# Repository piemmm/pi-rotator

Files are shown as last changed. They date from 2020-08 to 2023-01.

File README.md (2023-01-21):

# pi-rotator
The GS-232 costs far too much, so here's a simple Pi based antenna rotator which uses through-hole components wherever possible

The project is CC-BY-SA 

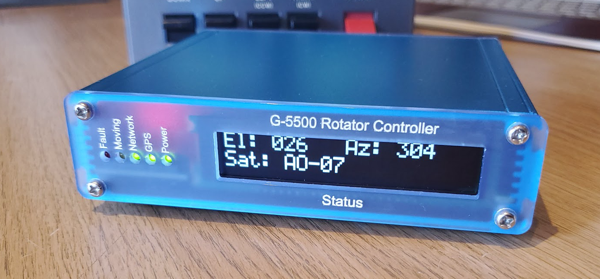
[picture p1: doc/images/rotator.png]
Picture of rotator

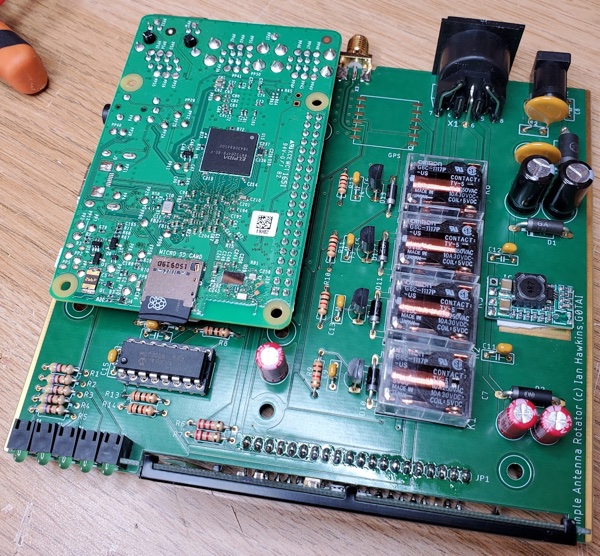
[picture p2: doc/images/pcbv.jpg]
Picture of rotator circuit board


This project is currently still EXPERIMENTAL until the board design is finalised, and the driver software made more useful.

Getting Started:

pirotator is installed in the default user home directory - you can change this if you want.

Create the pirotator directory and change into it:

````
mkdir /home/pi/pirotator
cd /home/pi/pirotator
````

extract the contents of the repository folder ./home/pirotator to /home/pi/pirotator (this contains config.xml, start.sh, etc)

Then, make start.sh executable (if it is not already):

````
chmod u+x start.sh
````

install java 8 (java11+ support available once pi4j is updated):
 
````
sudo apt install openjdk-8-jdk
````

Copy the pirotator.service to systemd (only if you want to start at boot):

````
sudo cp pirotator.service /etc/systemd/system/pirotator.service
````

Then, enable the service

````
sudo systemctl enable pirotator.service
````

After that you should be good to go and can type:

````
sudo service pirotator.service start
````

To enable PPS + GPS + NTPd so you can have your own stratum one equivalent server:

Install the relevant bits:

````
sudo apt install gpsd gpsd-clients python-gi-cairo pps-tools ntp
````

Add this to /boot/config.txt

````
dtoverlay=pps-gpio,gpiopin=4,capture_clear
````

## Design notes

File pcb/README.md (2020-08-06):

The PCB files are created with Eagle PCB and the design is CC-BY-SA.

This is still experimental.

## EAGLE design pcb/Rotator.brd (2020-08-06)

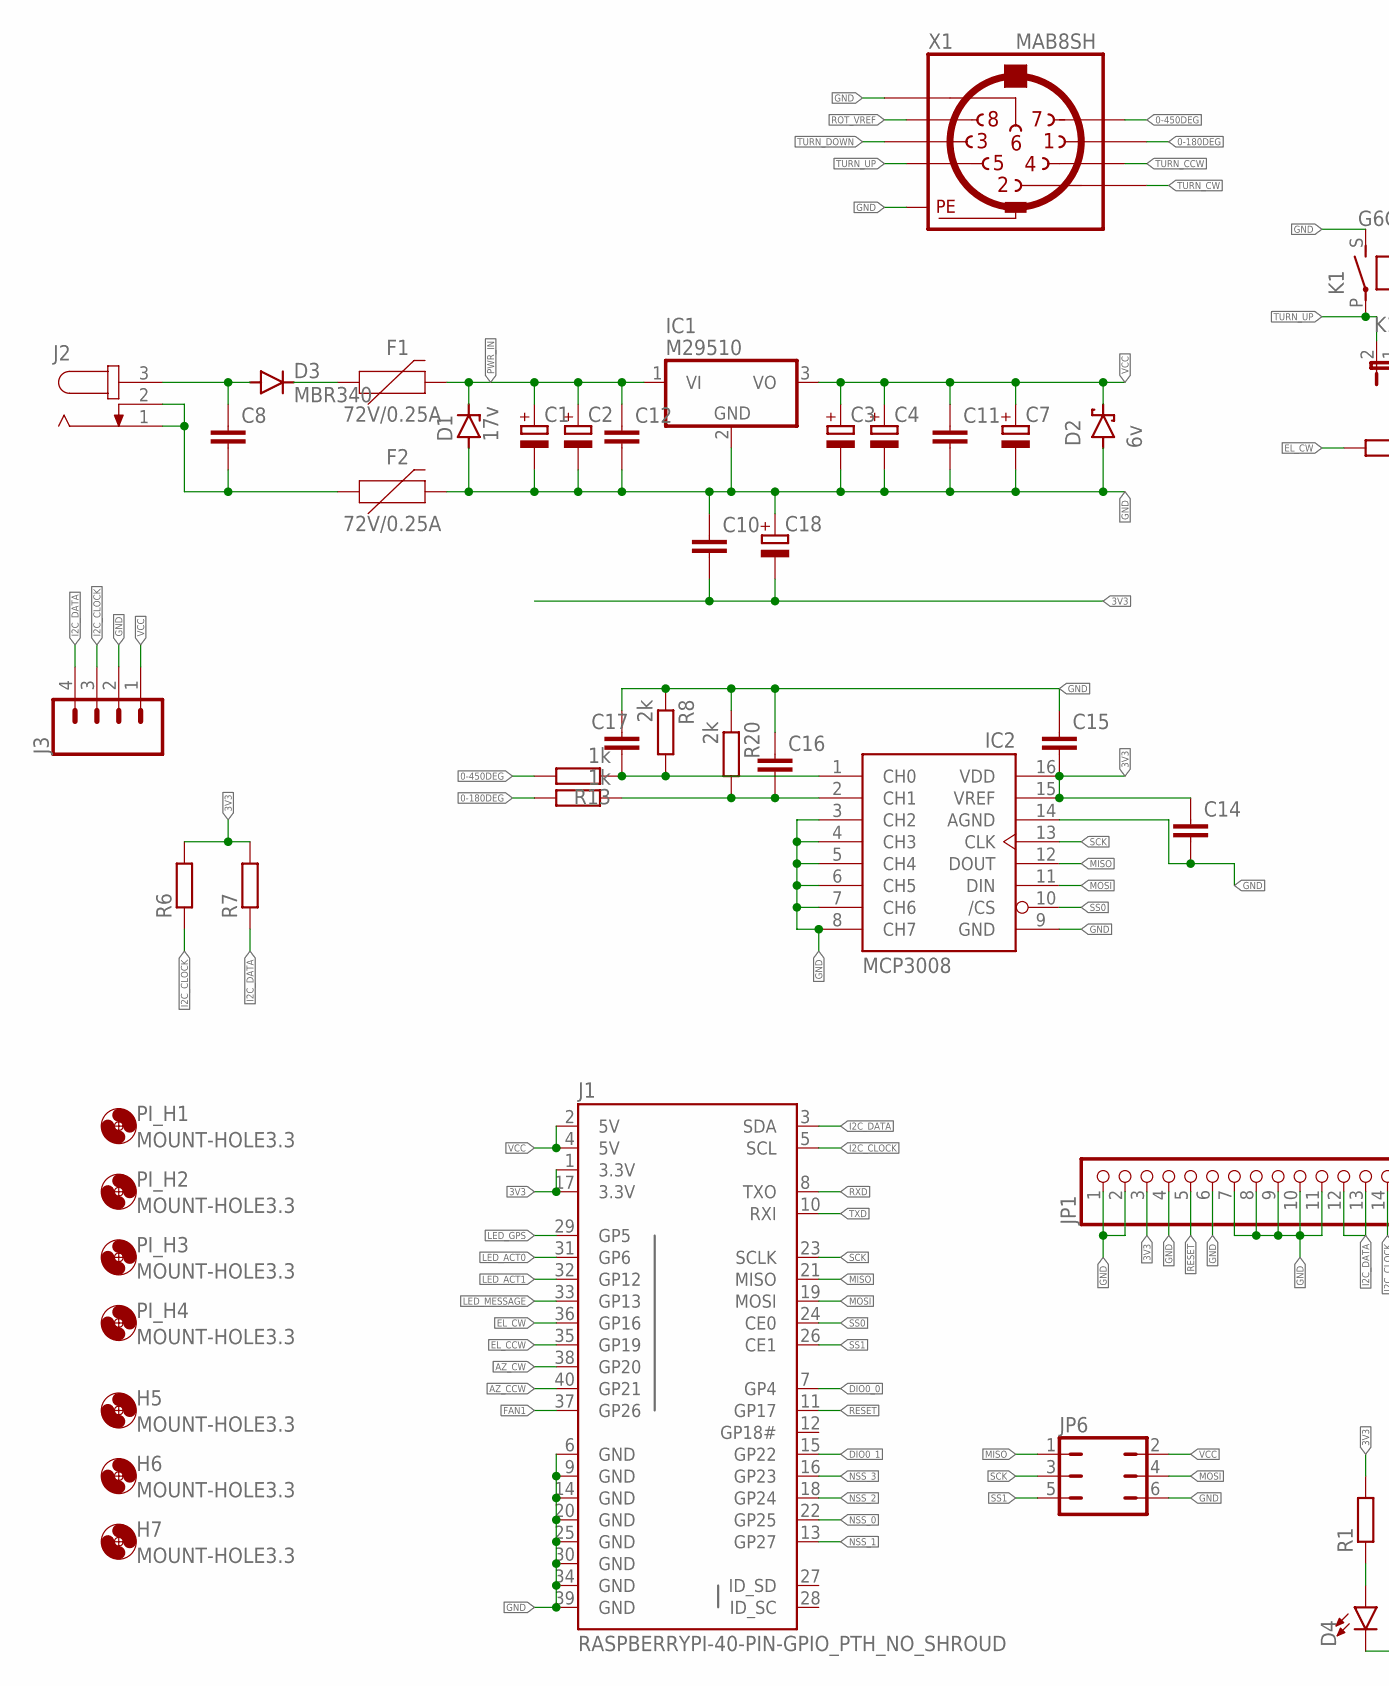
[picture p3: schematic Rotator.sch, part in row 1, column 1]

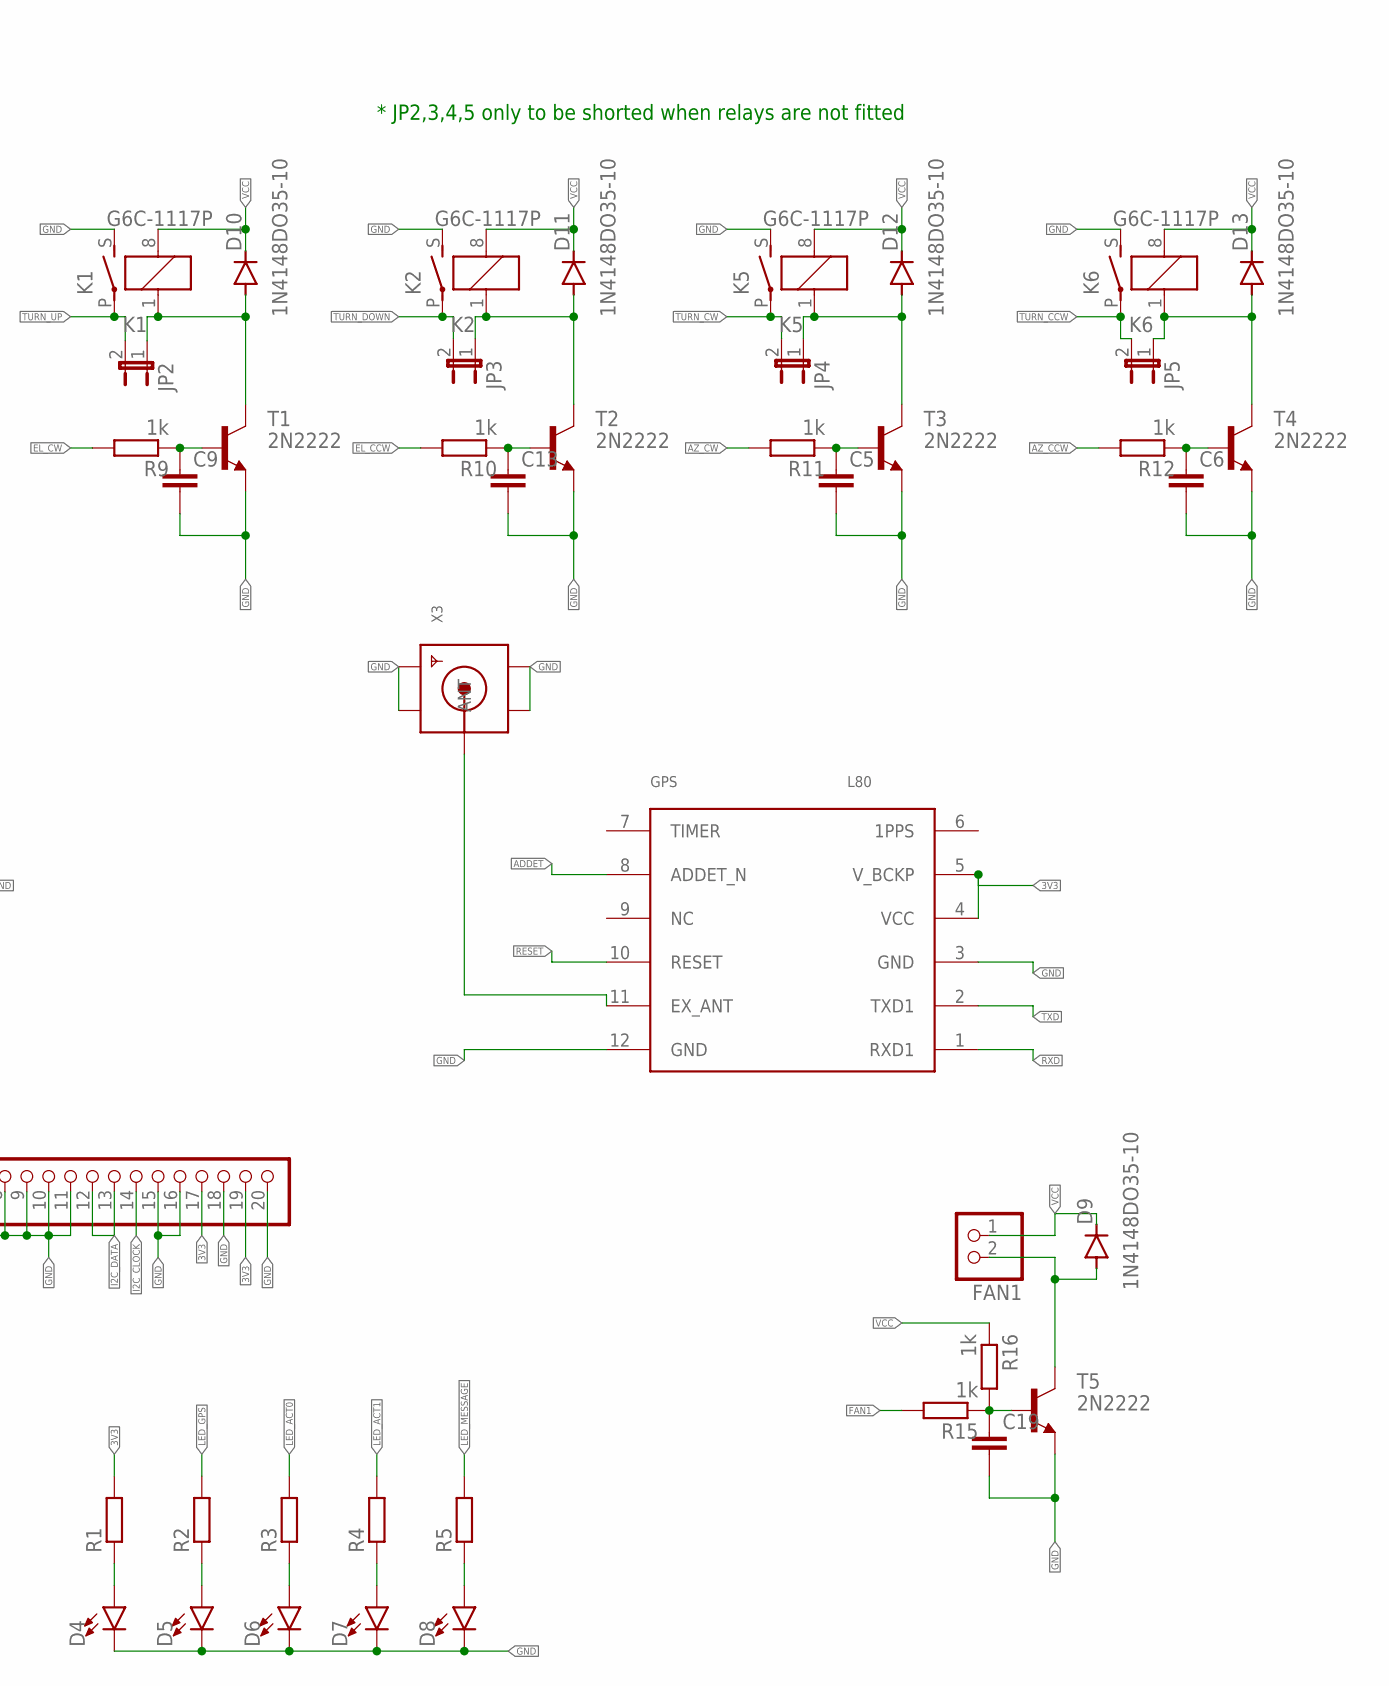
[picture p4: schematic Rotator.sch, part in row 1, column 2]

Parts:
C1, C2: CPOL-EUE5-8.5; E5-8,5
C3, C4, C7, C18: CPOL-EUE2.5-7; E2,5-7
C5, C6, C8, C9, C10, C11, C12, C13, C14, C15, C16, C17, C19: C-EU050-025X075; C050-025X075
D1: 17v; F126Z12
D2: 6v; F126Z12
D3: MBR340; DO201-15
D4, D5, D6, D7, D8: LED3MM; LED_3MM
D9, D10, D11, D12, D13: 1N4148DO35-10; DO35-10
F1, F2: 72V/0.25A; PTH
FAN1: JST_2PIN-THM; JST-PH-2-THM
GPS: L80
H5, H6, H7: MOUNT-HOLE3.3; 3,3
IC1: M29510; TO220H
IC2: MCP3008; DIL16
J1: RASPBERRYPI-40-PIN-GPIO_PTH_NO_SHROUD; 2X20
J2: JACK-PLUG0; SPC4077
J3: CONN_04; 1X04
JP1: PINHD-1X20; 1X20
JP2, JP3, JP4, JP5: JP1E; JP1
JP6: JP3Q
K1, K2, K5, K6: G6C-1117P
PI_H1, PI_H2, PI_H3, PI_H4: MOUNT-HOLE3.3; 3,3
R1, R2, R3, R4, R5, R6, R7: R-EU_0207/10; 0207/10
R8, R20: 2k; 0207/10
R9, R10, R11, R12, R13, R14, R15, R16: 1k; 0207/10
T1, T2, T3, T4, T5: 2N2222; TO92-EBC-OVAL
X1: MAB8SH
X3: SMACONNECTOR_EDGE; SMA_EDGELAUNCH

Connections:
0-180DEG: R14.2, X1.1
0-450DEG: R13.2, X1.7
3V3: C10.2, C14.1, C15.2, C18.-, GPS.4 (VCC), GPS.5 (V_BCKP), IC2.15 (VREF), IC2.16 (VDD), J1.1 (3.3V), J1.17 (3.3V), JP1.3, JP1.17, JP1.19, R1.2, R6.2, R7.2
ADDET: GPS.8 (ADDET_N)
AZ_CCW: J1.40 (GP21), R12.2
AZ_CW: J1.38 (GP20), R11.2
DIO0_0: J1.7 (GP4)
DIO0_1: J1.15 (GP22)
EL_CCW: J1.35 (GP19), R10.2
EL_CW: J1.36 (GP16), R9.2
FAN1: J1.37 (GP26), R15.2
FANHDR-: D9.A, FAN1.2 (1), T5.C
GND: C1.-, C2.-, C3.-, C4.-, C5.2, C6.2, C7.-, C9.2, C10.1, C11.2, C12.2, C13.2, C14.2, C15.1, C16.1, C17.1, C18.+, C19.2, D1.A, D2.A, D4.K (C), D5.K (C), D6.K (C), D7.K (C), D8.K (C), F2.P$2 (2), GPS.3 (GND), GPS.12 (GND), IC1.2 (GND), IC2.3 (CH2), IC2.4 (CH3), IC2.5 (CH4), IC2.6 (CH5), IC2.7 (CH6), IC2.8 (CH7), IC2.9 (GND), IC2.14 (AGND), J1.6 (GND), J1.9 (GND), J1.14 (GND), J1.20 (GND), J1.25 (GND), J1.30 (GND), J1.34 (GND), J1.39 (GND), J3.2, JP1.1, JP1.2, JP1.4, JP1.6, JP1.7, JP1.8, JP1.9, JP1.10, JP1.11, JP1.15, JP1.16, JP1.18, JP1.20, JP6.6, K1.S, K2.S, K5.S, K6.S, R8.1, R20.1, T1.E, T2.E, T3.E, T4.E, T5.E, X1.6, X1.PE, X1.PE@ (PE), X3.GND@1 (GND4), X3.GND@2 (GND3), X3.GND@3 (GND2), X3.GND@4 (GND1)
I2C_CLOCK: J1.5 (SCL), J3.3, JP1.14, R6.1
I2C_DATA: J1.3 (SDA), J3.4, JP1.12, JP1.13, R7.1
LED_ACT0: J1.31 (GP6), R3.2
LED_ACT1: J1.32 (GP12), R4.2
LED_GPS: J1.29 (GP5), R2.2
LED_MESSAGE: J1.33 (GP13), R5.2
MISO: IC2.12 (DOUT), J1.21 (MISO), JP6.1
MOSI: IC2.11 (DIN), J1.19 (MOSI), JP6.4
unnamed: C5.1, R11.1, T3.B
unnamed: D12.A, JP4.1, K5.1, T3.C
unnamed: C8.1, D3.A, J2.3
unnamed: C8.2, F2.P$1 (1), J2.1, J2.2
unnamed: GPS.11 (EX_ANT), X3.P (ANT)
unnamed: C13.1, R10.1, T2.B
unnamed: D3.C, F1.P$1 (1)
unnamed: C6.1, R12.1, T4.B
unnamed: C19.1, R15.1, R16.2, T5.B
unnamed: D13.A, JP5.1, K6.1, T4.C
unnamed: D4.A, R1.1
unnamed: D5.A, R2.1
unnamed: D6.A, R3.1
unnamed: D7.A, R4.1
unnamed: D8.A, R5.1
unnamed: C9.1, R9.1, T1.B
unnamed: D10.A, JP2.1, K1.1, T1.C
unnamed: D11.A, JP3.1, K2.1, T2.C
unnamed: C17.2, IC2.1 (CH0), R8.2, R13.1
unnamed: C16.2, IC2.2 (CH1), R14.1, R20.2
NSS_0: J1.22 (GP25)
NSS_1: J1.13 (GP27)
NSS_2: J1.18 (GP24)
NSS_3: J1.16 (GP23)
PWR_IN: C1.+, C2.+, C12.1, D1.C, F1.P$2 (2), IC1.1 (VI)
RESET: GPS.10 (RESET), J1.11 (GP17), JP1.5
ROT_VREF: X1.8
RXD: GPS.1 (RXD1), J1.8 (TXO)
SCK: IC2.13 (CLK), J1.23 (SCLK), JP6.3
SS0: IC2.10 (/CS), J1.24 (CE0)
SS1: J1.26 (CE1), JP6.5
TURN_CCW: JP5.2, K6.P, X1.4
TURN_CW: JP4.2, K5.P, X1.2
TURN_DOWN: JP3.2, K2.P, X1.3
TURN_UP: JP2.2, K1.P, X1.5
TXD: GPS.2 (TXD1), J1.10 (RXI)
VCC: C3.+, C4.+, C7.+, C11.1, D2.C, D9.C, D10.C, D11.C, D12.C, D13.C, FAN1.1 (2), IC1.3 (VO), J1.2 (5V), J1.4 (5V), J3.1, JP6.2, K1.8 (2), K2.8 (2), K5.8 (2), K6.8 (2), R16.1

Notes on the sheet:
* JP2,3,4,5 only to be shorted when relays are not fitted

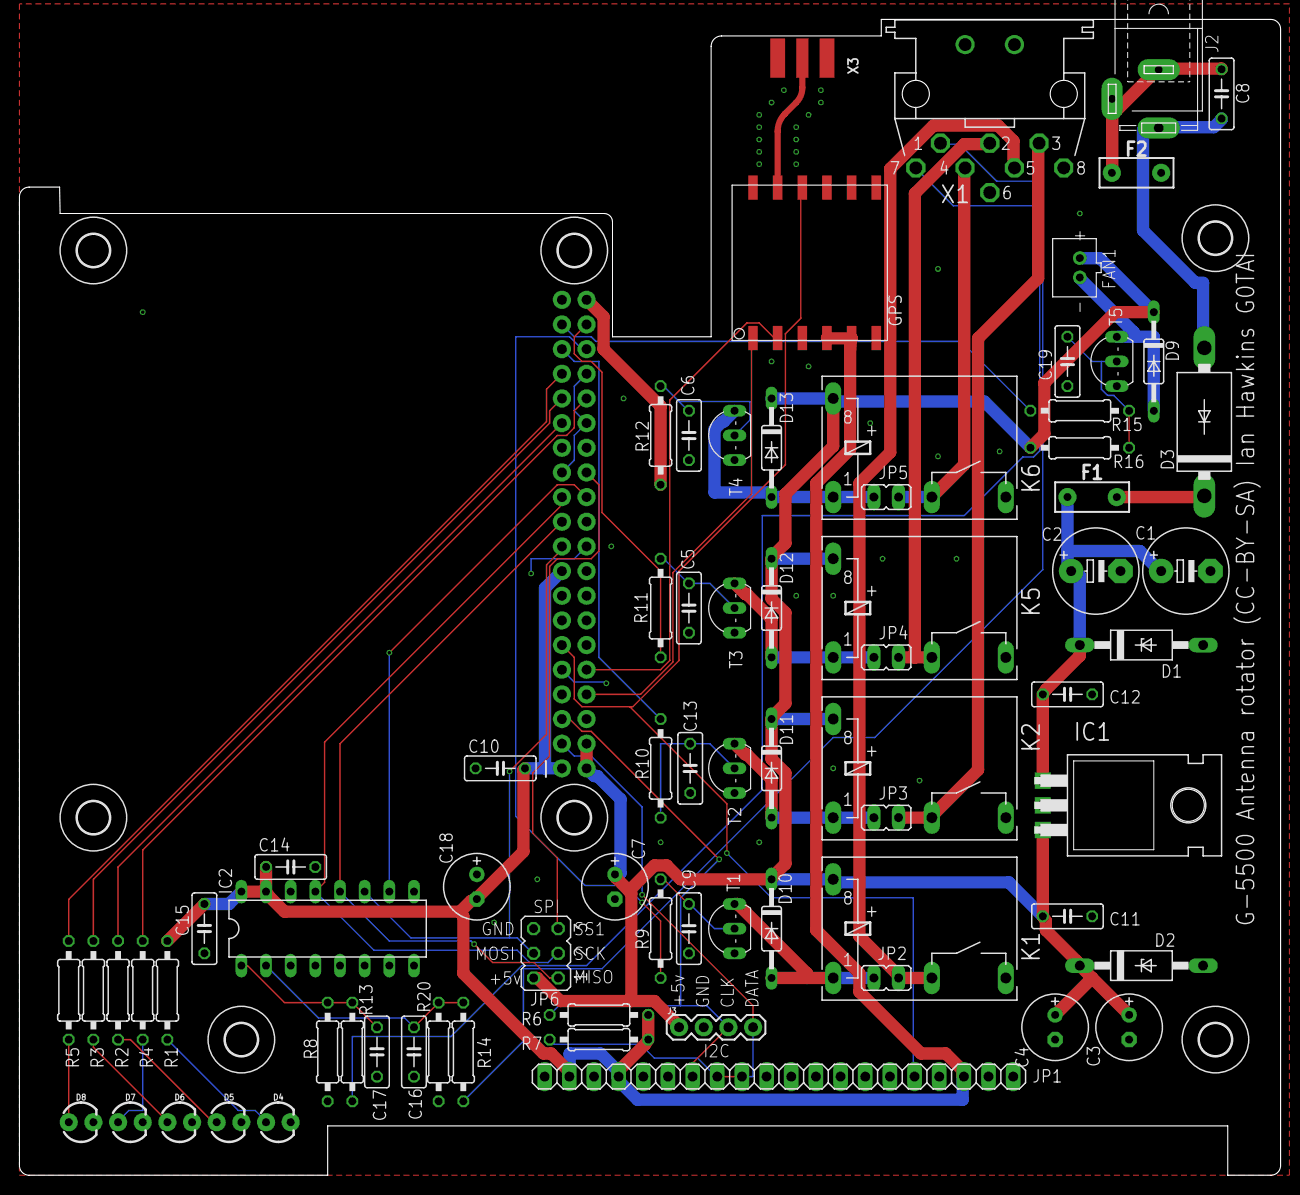
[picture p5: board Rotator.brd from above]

Board: 2 copper layers, 129.9 x 119.0 mm, 82 parts (1 on the bottom side), 50 nets.

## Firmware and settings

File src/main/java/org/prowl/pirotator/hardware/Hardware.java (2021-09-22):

package org.prowl.pirotator.hardware;

import java.io.IOException;
import java.util.concurrent.Semaphore;

import org.apache.commons.logging.Log;
import org.apache.commons.logging.LogFactory;

import com.pi4j.io.gpio.GpioController;
import com.pi4j.io.gpio.GpioFactory;
import com.pi4j.io.gpio.GpioPinDigitalOutput;
import com.pi4j.io.gpio.Pin;
import com.pi4j.io.gpio.PinState;
import com.pi4j.io.gpio.RaspiPin;
import com.pi4j.io.i2c.I2CDevice;
import com.pi4j.io.i2c.I2CFactory;
import com.pi4j.io.spi.SpiChannel;
import com.pi4j.io.spi.SpiDevice;
import com.pi4j.io.spi.SpiFactory;
import com.pi4j.io.spi.SpiMode;

/**
 * Single class to access the hardware
 */
public enum Hardware {

   INSTANCE;

   private final Log            LOG          = LogFactory.getLog("Hardware");

   private float                MAX_CPU_TEMP = 75f;

   private final Semaphore      spiLock      = new Semaphore(1, true);
   private SpiDevice            spi;

   private Pin                  ss0          = RaspiPin.GPIO_06;
   private Pin                  ss1          = RaspiPin.GPIO_02;

   private Pin                  reset        = RaspiPin.GPIO_00;

   private Pin                  el_cw        = RaspiPin.GPIO_27;
   private Pin                  el_ccw       = RaspiPin.GPIO_24;
   private Pin                  az_cw        = RaspiPin.GPIO_28;
   private Pin                  az_ccw       = RaspiPin.GPIO_29;

   private Pin                  fan          = RaspiPin.GPIO_25;

   private Pin                  fault        = RaspiPin.GPIO_23;
   private Pin                  network      = RaspiPin.GPIO_22;
   private Pin                  moving       = RaspiPin.GPIO_26;
   private Pin                  gps          = RaspiPin.GPIO_21;

   private GpioPinDigitalOutput gpioFault;
   private GpioPinDigitalOutput gpioNetwork;
   private GpioPinDigitalOutput gpioMoving;
   private GpioPinDigitalOutput gpioGPS;

   private GpioController       gpio;
   private GpioPinDigitalOutput gpioSS0;
   private GpioPinDigitalOutput gpioSS1;
   private GpioPinDigitalOutput gpioRst;
   private GpioPinDigitalOutput gpioFan;

   private GpioPinDigitalOutput gpioElCW;
   private GpioPinDigitalOutput gpioElCCW;
   private GpioPinDigitalOutput gpioAzCW;
   private GpioPinDigitalOutput gpioAzCCW;

   private Hardware() {
      try {
         spi = SpiFactory.getInstance(SpiChannel.CS0, 1_000_000, SpiMode.MODE_0);

         gpio = GpioFactory.getInstance();

         // Select pin 0
         gpioSS0 = gpio.provisionDigitalOutputPin(ss0, PinState.HIGH);
         gpioSS0.setShutdownOptions(true, PinState.HIGH);
         gpioSS0.high();

         // Select pin 1
         gpioSS1 = gpio.provisionDigitalOutputPin(ss1, PinState.HIGH);
         gpioSS1.setShutdownOptions(true, PinState.HIGH);
         gpioSS1.low();

         // Elevation Clockwise
         gpioElCW = gpio.provisionDigitalOutputPin(el_cw, PinState.LOW);
         gpioElCW.setShutdownOptions(true, PinState.LOW);
         gpioElCW.low();

         // Elevation Counter Clockwise
         gpioElCCW = gpio.provisionDigitalOutputPin(el_ccw, PinState.LOW);
         gpioElCCW.setShutdownOptions(true, PinState.LOW);
         gpioElCCW.low();

         // Azimuth Clockwise
         gpioAzCW = gpio.provisionDigitalOutputPin(az_cw, PinState.LOW);
         gpioAzCW.setShutdownOptions(true, PinState.LOW);
         gpioAzCW.low();

         // Azimuth Counter Clockwise
         gpioAzCCW = gpio.provisionDigitalOutputPin(az_ccw, PinState.LOW);
         gpioAzCCW.setShutdownOptions(true, PinState.LOW);
         gpioAzCCW.low();

         // Fan/Blower
         gpioFan = gpio.provisionDigitalOutputPin(fan, PinState.HIGH);
         gpioFan.setShutdownOptions(true, PinState.HIGH); // Fan always on if no thermal monitor running
         gpioFan.high();

         // Fault redLED - should be on if app is ever not running
         gpioFault = gpio.provisionDigitalOutputPin(fault, PinState.LOW);
         gpioFault.setShutdownOptions(false, PinState.HIGH);

         // Network led - active when an API sending rotate requests
         gpioNetwork = gpio.provisionDigitalOutputPin(network, PinState.LOW);
         gpioNetwork.setShutdownOptions(true, PinState.LOW);

         // GPS - flashes when searching, solid when 3d Fixed
         gpioGPS = gpio.provisionDigitalOutputPin(gps, PinState.LOW);
         gpioGPS.setShutdownOptions(true, PinState.LOW);

         // Moving LED - active when the rotator is being moved.
         gpioMoving = gpio.provisionDigitalOutputPin(moving, PinState.LOW);
         gpioMoving.setShutdownOptions(true, PinState.LOW);

         // Reset (default being reset until we're ready). This also is commoned with the
         // RF modules reset pin.
         gpioRst = gpio.provisionDigitalOutputPin(reset, PinState.HIGH);
         gpioRst.setShutdownOptions(true, PinState.LOW); // If the VM exits or something quits us, we make sure the SX modules can't
                                                         // transmit
         gpioRst.low();
         resetAll();

      } catch (IOException e) {
         LOG.error(e.getMessage(), e);
      }

   }

   public I2CDevice getI2CDevice(int addr) throws IOException, I2CFactory.UnsupportedBusNumberException {
      return I2CFactory.getInstance(1).getDevice(addr);
   }

   public final Semaphore getSPILock() {
      return spiLock;
   }

   public final SpiDevice getSPI() {
      return spi;
   }

   public GpioPinDigitalOutput getGpioSS0() {
      return gpioSS0;
   }

   public GpioPinDigitalOutput getGpioSS1() {
      return gpioSS1;
   }

   public void resetAll() {
      LOG.debug("Reset issued to devices");
      try {
         Thread.sleep(50);
      } catch (InterruptedException e) {
      }
      gpioRst.low();
      try {
         Thread.sleep(150);
      } catch (InterruptedException e) {
      }
      gpioRst.high();
      try {
         Thread.sleep(150);
      } catch (InterruptedException e) {
      }
   }

   public GpioPinDigitalOutput getGpioElCW() {
      return gpioElCW;
   }

   public GpioPinDigitalOutput getGpioElCCW() {
      return gpioElCCW;
   }

   public GpioPinDigitalOutput getGpioAzCW() {
      return gpioAzCW;
   }

   public GpioPinDigitalOutput getGpioAzCCW() {
      return gpioAzCCW;
   }

   public GpioPinDigitalOutput getFan() {
      return gpioFan;
   }

   public GpioPinDigitalOutput getGpioNetwork() {
      return gpioNetwork;
   }

   public GpioPinDigitalOutput getGpioMoving() {
      return gpioMoving;
   }

   public GpioPinDigitalOutput getGpioGPS() {
      return gpioGPS;
   }

   public GpioPinDigitalOutput getGpioFault() {
      return gpioFault;
   }

}

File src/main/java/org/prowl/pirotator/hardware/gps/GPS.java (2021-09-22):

package org.prowl.pirotator.hardware.gps;

import java.io.BufferedOutputStream;
import java.io.File;
import java.io.FileOutputStream;
import java.io.IOException;
import java.util.LinkedList;

import org.apache.commons.configuration.HierarchicalConfiguration;
import org.apache.commons.logging.Log;
import org.apache.commons.logging.LogFactory;
import org.prowl.pirotator.PiRotator;

import com.pi4j.io.serial.Baud;
import com.pi4j.io.serial.DataBits;
import com.pi4j.io.serial.FlowControl;
import com.pi4j.io.serial.Parity;
import com.pi4j.io.serial.Serial;
import com.pi4j.io.serial.SerialConfig;
import com.pi4j.io.serial.SerialFactory;
import com.pi4j.io.serial.SerialPort;
import com.pi4j.io.serial.StopBits;

import net.sf.marineapi.nmea.event.SentenceEvent;
import net.sf.marineapi.nmea.event.SentenceListener;
import net.sf.marineapi.nmea.io.SentenceReader;
import net.sf.marineapi.nmea.parser.SentenceFactory;
import net.sf.marineapi.nmea.util.Date;
import net.sf.marineapi.nmea.util.GpsFixStatus;
import net.sf.marineapi.nmea.util.Position;
import net.sf.marineapi.nmea.util.Time;
import net.sf.marineapi.provider.HeadingProvider;
import net.sf.marineapi.provider.PositionProvider;
import net.sf.marineapi.provider.SatelliteInfoProvider;
import net.sf.marineapi.provider.event.HeadingEvent;
import net.sf.marineapi.provider.event.HeadingListener;
import net.sf.marineapi.provider.event.PositionEvent;
import net.sf.marineapi.provider.event.ProviderListener;
import net.sf.marineapi.provider.event.SatelliteInfoEvent;
import net.sf.marineapi.provider.event.SatelliteInfoListener;

public class GPS {

   private static final Log          LOG = LogFactory.getLog("GPS");

   private HierarchicalConfiguration config;
   private Serial                    serial;
   private SentenceFactory           sf;
   private static Position           currentPosition;
   private static Double             currentCourse;
   private static Double             currentHeading;
   private static Double             currentSpeed;
   private static Time               currentTime;
   private static Date               currentDate;

   private GPSWriter                 gpsWriterThread;
   private BufferedOutputStream      gpsOutput;

   public GPS(HierarchicalConfiguration config) {
      this.config = config;
      sf = SentenceFactory.getInstance();

      // Create fifo pipes so gpsd can play with the GPS and PPS signals.
      // We will fix the output using a socat kludge so we can get data both ways
      String input = "gps0";
      String output = "gps0";
      try {
         createFifoPipe(input);
         // createFifoPipe(output);
      } catch (IOException e) {
         LOG.error(e.getMessage(), e);
      }

      gpsWriterThread = new GPSWriter(output);
      gpsWriterThread.start();
   }

   public void start() throws IOException {

      LOG.info("GPS Listener starting");

      serial = SerialFactory.createInstance();

      // create serial config object
      SerialConfig config = new SerialConfig();

      try {

         config.device(SerialPort.getDefaultPort())
               .baud(Baud._9600)
               .dataBits(DataBits._8)
               .parity(Parity.NONE)
               .stopBits(StopBits._1)
               .flowControl(FlowControl.NONE);

         // open the default serial device/port with the configuration settings
         serial.open(config);

      } catch (Throwable e) {
         // Try 3B+
         try {
            config.device("/dev/ttyS0")
                  .baud(Baud._9600)
                  .dataBits(DataBits._8)
                  .parity(Parity.NONE)
                  .stopBits(StopBits._1)
                  .flowControl(FlowControl.NONE);
            serial.open(config);
         } catch (Throwable ex) {
            // Rethrow as IOE
            throw new IOException(e);
         }

      }

      SentenceReader reader = new SentenceReader(serial.getInputStream());
      HeadingProvider provider = new HeadingProvider(reader);
      provider.addListener(new HeadingListener() {

         @Override
         public void providerUpdate(HeadingEvent evt) {
            currentHeading = evt.getHeading();
         }
      });

      PositionProvider pprovider = new PositionProvider(reader);
      pprovider.addListener(new ProviderListener<PositionEvent>() {

         @Override
         public void providerUpdate(PositionEvent evt) {
            currentPosition = evt.getPosition();
            currentTime = evt.getTime();
            currentCourse = evt.getCourse();
            currentSpeed = evt.getSpeed();
            currentDate = evt.getDate();
         }
      });

      SatelliteInfoProvider sprovider = new SatelliteInfoProvider(reader);
      sprovider.addListener(new SatelliteInfoListener() {

         @Override
         public void providerUpdate(SatelliteInfoEvent evt) {
            GpsFixStatus status = evt.getGpsFixStatus();
            if (status == GpsFixStatus.GPS_NA || status == GpsFixStatus.GPS_2D) {
               // Pulse GPS led until locked
               PiRotator.INSTANCE.getStatus().pulseGPS(150);
               currentPosition = null;
            } else if (status == GpsFixStatus.GPS_3D) {
               // LED on all the time
               PiRotator.INSTANCE.getStatus().pulseGPS(1500);
            }
         }

      });

      reader.addSentenceListener(new SentenceListener() {

         @Override
         public void sentenceRead(SentenceEvent event) {
            // Forward the sentence to our fifo socket
            gpsWriterThread.addData(event.getSentence().toString() + "\r\n");

            pprovider.readingStarted(); // Bugfix: https://github.com/ktuukkan/marine-api/issues/129
         }

         @Override
         public void readingStopped() {

         }

         @Override
         public void readingStarted() {

         }

         @Override
         public void readingPaused() {

         }
      });

      reader.start();

   }

   public void stop() {

   }

   /**
    * Returns the current known position, or null if no fix
    *
    * @return
    */
   public static Position getCurrentPosition() {
      return currentPosition;
   }

   public static Time getCurrentTime() {
      return currentTime;
   }

   public static Double getCurrentCourse() {
      return currentCourse;
   }

   public static Double getCurrentHeading() {
      return currentHeading;
   }

   public static Double getCurrentSpeed() {
      return currentSpeed;
   }

   public static Date getCurrentDate() {
      return currentDate;
   }

   public String getName() {
      return getClass().getSimpleName();
   }

   private class GPSWriter extends Thread {

      private LinkedList<String> toSend;
      private Object             MONITOR = new Object();
      private String             output;

      public GPSWriter(String output) {
         toSend = new LinkedList<>();
         this.output = output;
      }
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

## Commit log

2020-07-25 Basics mostly done waiting on new PCB.
2020-08-03 Refactor code out of the ADC class into a more appropriate location
2020-08-06 Initial PCB designs
    [Rotator.brd, Rotator.sch]
2020-08-06 Bugfixes, config update, doc image added
    [GPS.java, Rotator.java]
2020-08-06 Add readme for pcbs
2020-08-06 Moving led now works correctly.
    [Rotator.java]
2021-09-22 Remove unneeded dio pins, add workaround for bug in nmea parser library, add constraints for mcp3008 a/d readings for noisy pots.
    [GPS.java, Hardware.java, Rotator.java]
2023-01-21 Add files via upload
    Rotator PCB

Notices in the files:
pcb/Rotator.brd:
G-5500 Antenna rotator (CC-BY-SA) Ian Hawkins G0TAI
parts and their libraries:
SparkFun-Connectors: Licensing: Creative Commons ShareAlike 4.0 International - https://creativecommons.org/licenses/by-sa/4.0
